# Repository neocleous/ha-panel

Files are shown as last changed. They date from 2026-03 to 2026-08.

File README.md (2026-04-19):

# HA Panel

Wall-mounted Home Assistant touch panel built on Raspberry Pi 5 with a Waveshare 8" DSI display.

HA runs on a separate server. Each panel is a pure display and sensor client — no HAOS on the panel itself.

---

## Hardware

| Component | Part |
|---|---|
| Compute | Raspberry Pi 5 (4GB) |
| Display | Waveshare 8inch DSI LCD (C), 1280×800 IPS |
| Touch controller | AT42QT1070 (custom PCB, I2C, 4 buttons) |
| Temp / humidity / pressure / VOC | BME680 breakout (I2C 0x76) |
| Proximity (screen wake) | VL53L0X breakout (I2C 0x29) |
| Ambient light | VEML6030 breakout (I2C 0x10) |
| Power | USB-C (Adafruit USB Type C Vertical Breakout or custom power board) |

All sensors connect directly to the Pi's I2C bus 1. No sensors are on the touch PCB.

---

## Repository layout

```
ha-panel/
├── sensor-daemon/
│   ├── main.py              # MQTT discovery + I2C polling loop
│   ├── config.py            # Your local config — NOT committed (see .gitignore)
│   ├── config.example.py    # Template — copy to config.py and fill in values
│   ├── backlight.py         # sysfs backlight control
│   ├── requirements.txt
│   └── sensors/
│       ├── at42qt1070.py    # Touch buttons (KEY0–KEY3)
│       ├── bme680.py        # Temp / humidity / pressure / VOC
│       ├── vl53l0x.py       # Proximity (ToF)
│       └── veml6030.py      # Ambient light
├── provisioning-ui/
│   ├── index.html           # Wi-Fi network list
│   ├── password.html        # Password entry + on-screen keyboard
│   └── server.py            # Local HTTP server (port 8080)
└── system/
    ├── install.sh           # Full install script for a new panel
    ├── startup.sh           # Kiosk startup: writes labwc config, launches labwc
    ├── update.sh            # Nightly update script
    ├── panel-update.timer   # systemd timer (2am)
    ├── panel-update.service
    └── sensor-daemon.service
```

---

## Configuration

Before running the sensor daemon, copy the example config and fill in your values:

```bash
cp /opt/ha-panel/repo/sensor-daemon/config.example.py \
   /opt/ha-panel/repo/sensor-daemon/config.py
nano /opt/ha-panel/repo/sensor-daemon/config.py
```

Set at minimum:
- `PANEL_ID` — must match the hostname (e.g. `panel-01`)
- `MQTT_BROKER` — your HA server IP
- `MQTT_USERNAME` / `MQTT_PASSWORD` — MQTT credentials from HA

The HA dashboard URL is set in `/opt/ha-panel/config`:

```bash
HA_URL=http://YOUR_HA_IP:8123
```

**Never commit `config.py` to the repo.** It is listed in `.gitignore`.

---

## Deploying a new panel

### Step 1 — Flash SD card

Use [Raspberry Pi Imager](https://www.raspberrypi.com/software/) with these settings:

| Setting | Value |
|---|---|
| OS | Raspberry Pi OS Lite (64-bit) |
| Hostname | `panel-01` (increment for each panel) |
| Username | *(your chosen username)* |
| Password | *(your chosen password)* |
| SSH | Enable — password authentication |
| Wi-Fi | Configure your network |
| Locale | Set your timezone and keyboard layout |

### Step 2 — Boot and SSH in

Insert the SD card, connect the DSI display, and power on. Wait ~60 seconds for first boot, then SSH in:

```bash
ssh yourusername@panel-01.local
# or use the IP address if mDNS isn't available
```

### Step 3 — Run the install script

```bash
curl -fsSL https://raw.githubusercontent.com/neocleous/ha-panel/main/system/install.sh \
  -o /tmp/install.sh && sudo bash /tmp/install.sh
```

The script will:

1. Detect your username automatically
2. Install all required packages
3. Configure the display overlay, I2C, Bluetooth disable, and autologin
4. Clone the repo to `/opt/ha-panel/repo`
5. Set up the Python venv
6. Configure the firewall
7. Offer to reboot

### Step 4 — Configure the panel

After the install, copy and edit the sensor daemon config:

```bash
cp /opt/ha-panel/repo/sensor-daemon/config.example.py \
   /opt/ha-panel/repo/sensor-daemon/config.py
nano /opt/ha-panel/repo/sensor-daemon/config.py
```

Then create the panel config file:

```bash
sudo nano /opt/ha-panel/config
```

Add:

```
HA_URL=http://YOUR_HA_IP:8123
```

Then reboot. The panel will start automatically.

---

## How it works

### Display stack

```
TTY1 autologin (.bash_profile)
  └── startup.sh
        ├── Sources /opt/ha-panel/config
        ├── Writes ~/.config/labwc/rc.xml  (touch mapping, window rules)
        ├── Writes ~/.config/labwc/autostart  (squeekboard + chromium loop)
        └── Launches labwc
              ├── squeekboard  (on-screen keyboard)
              └── chromium --app=HA_URL (kiosk, maximised, no decorations)
```

### Sensor daemon

Runs as a system service (`sensor-daemon.service`). On startup it publishes MQTT discovery messages so all entities appear automatically in HA under the panel's device. It then polls sensors every ~5 seconds and publishes readings.

Entities registered per panel:

| Entity | Type |
|---|---|
| Temperature | Sensor |
| Humidity | Sensor |
| Pressure | Sensor |
| VOC | Sensor |
| Light | Sensor |
| Proximity | Sensor |
| Button 0–3 | Binary sensor |
| Backlight | Switch |

MQTT topics follow the pattern: `home/{panel-id}/sensor/*`

### Nightly updates

A systemd timer fires at 2:00–2:05am. The update script:

1. Turns the screen off
2. Runs `apt upgrade`
3. Updates `rpi-eeprom`
4. Upgrades Python packages in the venv
5. Pulls the latest repo via `git reset --hard origin/main`
6. Reboots if the kernel or eeprom changed

### Wi-Fi provisioning

If the panel boots without a network connection, `startup.sh` starts the provisioning server on port 8080 and loads `http://localhost:8080` in Chromium instead of HA.

---

## SSH access

Each panel accepts SSH from the local network only (firewall rule: `192.168.1.0/24`).

```bash
ssh yourusername@panel-01.local
ssh yourusername@panel-02.local
```

---

## Adding a second panel to HA

No manual HA configuration is needed. When the sensor daemon starts on a new panel it publishes MQTT discovery messages automatically. The new panel will appear in:

**HA → Settings → Devices & Services → MQTT → Devices**

---

## Troubleshooting

### Touchscreen not working after reboot

Confirm autologin is active:

```bash
sudo raspi-config nonint get_autologin
# Should return: 1
```

### On-screen keyboard not appearing

Chromium must be launched with `--app=URL --start-maximized` (not `--kiosk`). Confirm:

```bash
pgrep -a chromium | grep "app="
```

### Sensor daemon not connecting to MQTT

Check the service logs:

```bash
sudo journalctl -u sensor-daemon --no-pager | tail -30
```

Verify the MQTT credentials in `sensor-daemon/config.py` match those in your HA MQTT integration.

### Backlight not controlled

Find the correct sysfs path:

```bash
ls /sys/class/backlight/
```

Update `BACKLIGHT_PATH` in `sensor-daemon/config.py` to match.

### Display not turning on

Verify the correct overlay is set in `/boot/firmware/config.txt`:

```
dtoverlay=vc4-kms-dsi-waveshare-panel,8_0_inch
```

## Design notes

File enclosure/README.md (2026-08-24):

# Enclosure

`HA Panel Final.step` — full enclosure model (Shapr3D export, 2026-08-24).

Printed on Bambu Lab X1C, 0.4 mm nozzle, 0.2 mm layer height.
Touch-board pocket expects the rev-C PCB (100 x 44 x 1.6 mm, flat front
face, no mounting holes — adhesive/press fit). Clearances are sized for
FDM (0.2 mm); increase to 0.4–0.5 mm before ordering SLS/MJF, resin can
keep 0.2 mm (0.3 mm on long mating edges).

Related: PCB source, BOM and assembly docs in `hardware/rev-c/` on this
branch.

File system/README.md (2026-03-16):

# HA Panel

Wall-mounted Home Assistant touch panel built on Raspberry Pi 5 with a Waveshare 8" DSI display.

HA runs on a separate server. Each panel is a pure display and sensor client — no HAOS on the panel itself.

---

## Hardware

| Component | Part |
|---|---|
| Compute | Raspberry Pi 5 (4GB) |
| Display | Waveshare 8inch DSI LCD (C), 1280×800 IPS |
| Touch controller | AT42QT1070 (custom PCB, I2C, 4 buttons) |
| Temp / humidity / pressure / VOC | BME680 breakout (I2C 0x76) |
| Proximity (screen wake) | VL53L0X breakout (I2C 0x29) |
| Ambient light | VEML6030 breakout (I2C 0x10) |
| Power | USB-C (custom power board) |

All sensors connect directly to the Pi's I2C bus 1. No sensors are on the touch PCB.

---

## Repository layout

```
ha-panel/
├── sensor-daemon/
│   ├── main.py              # MQTT discovery + I2C polling loop
│   ├── config.py            # All configurable values
│   ├── backlight.py         # sysfs backlight control
│   ├── requirements.txt
│   └── sensors/
│       ├── at42qt1070.py    # Touch buttons (KEY0–KEY3)
│       ├── bme680.py        # Temp / humidity / pressure / VOC
│       ├── vl53l0x.py       # Proximity (ToF)
│       └── veml6030.py      # Ambient light
├── provisioning-ui/
│   ├── index.html           # Wi-Fi network list
│   ├── password.html        # Password entry + on-screen keyboard
│   └── server.py            # Local HTTP server (port 8080)
└── system/
    ├── install.sh           # Full install script for a new panel
    ├── startup.sh           # Kiosk startup: writes labwc config, launches labwc
    ├── update.sh            # Nightly update script
    ├── panel-update.timer   # systemd timer (2am)
    ├── panel-update.service
    └── sensor-daemon.service
```

---

## Deploying a new panel

### Step 1 — Flash SD card

Use [Raspberry Pi Imager](https://www.raspberrypi.com/software/) with these settings:

| Setting | Value |
|---|---|
| OS | Raspberry Pi OS Lite (64-bit) |
| Hostname | `panel-02` (increment for each panel) |
| Username | `pi` |
| Password | *(your chosen password)* |
| SSH | Enable — password authentication |
| Wi-Fi | Configure your network |
| Locale | Set your timezone and keyboard layout |

### Step 2 — Boot and SSH in

Insert the SD card, connect the DSI display, and power on. Wait ~60 seconds for first boot, then SSH in:

```bash
ssh pi@panel-02.local
# or use the IP address if mDNS isn't available
```

### Step 3 — Run the install script

You need a GitHub Personal Access Token (PAT) with `repo` read scope to download the script from the private repo. Create one at: https://github.com/settings/tokens

Then run:

```bash
curl -fsSL \
  -H "Authorization: token YOUR_GITHUB_PAT" \
  "https://raw.githubusercontent.com/neocleous/ha-panel/main/system/install.sh" \
  | sudo bash
```

The script will:

1. Install all required packages
2. Configure the display overlay, I2C, Bluetooth disable, and autologin
3. Generate a unique SSH deploy key for this panel
4. **Pause and show you the public key** — add it to GitHub before continuing
5. Clone the repo to `/opt/ha-panel/repo`
6. Set up the Python venv and install sensor daemon dependencies
7. Enable the sensor daemon and nightly update timer
8. Configure the firewall
9. Offer to reboot

### Step 4 — Add the deploy key to GitHub

When the script pauses, it will display the public key and instructions. Go to:

**https://github.com/neocleous/ha-panel/settings/keys → Add deploy key**

- Title: the panel ID (e.g. `panel-02`)
- Key: paste the public key shown by the script
- Allow write access: **leave unchecked**

Press Enter in the terminal to continue.

### Step 5 — Reboot

The script will offer to reboot. After reboot the panel will automatically:

- Log in as `pi` on TTY1
- Launch labwc (Wayland compositor)
- Start Chromium in app mode pointing at HA
- Register all sensors with HA via MQTT discovery

---

## How it works

### Display stack

```
TTY1 autologin (.bash_profile)
  └── startup.sh
        ├── Writes ~/.config/labwc/rc.xml  (touch mapping, window rules)
        ├── Writes ~/.config/labwc/autostart  (squeekboard + chromium loop)
        └── Launches labwc
              ├── squeekboard  (on-screen keyboard)
              └── chromium --app=http://HA_URL (kiosk, maximised, no decorations)
```

### Sensor daemon

Runs as a system service (`sensor-daemon.service`). On startup it publishes MQTT discovery messages so all entities appear automatically in HA under the panel's device. It then polls sensors every ~5 seconds and publishes readings.

Entities registered per panel:

| Entity | Type |
|---|---|
| Temperature | Sensor |
| Humidity | Sensor |
| Pressure | Sensor |
| VOC | Sensor |
| Light | Sensor |
| Proximity | Sensor |
| Button 0–3 | Binary sensor |
| Backlight | Switch |

MQTT topics follow the pattern: `home/{panel-id}/sensor/*`

### Nightly updates

A systemd timer fires at 2:00–2:05am (random stagger between panels). The update script:

1. Turns the screen off
2. Runs `apt upgrade`
3. Updates `rpi-eeprom`
4. Upgrades Python packages in the venv
5. Pulls the latest repo via `git reset --hard origin/main`
6. Reboots if the kernel, eeprom, or repo changed

### Wi-Fi provisioning

If the panel boots without a network connection, `startup.sh` starts the provisioning server on port 8080 and loads `http://localhost:8080` in Chromium instead of HA. The provisioning UI shows available networks and a touch keyboard for password entry.

---

## Configuration

All configurable values are in `sensor-daemon/config.py`:

```python
PANEL_ID = "panel-01"       # Must match hostname
HA_URL   = "http://192.168.1.x:8123"
MQTT_HOST = "192.168.1.x"
MQTT_PORT = 1883
MQTT_USER = "ha-panel"
MQTT_PASS = "your-password"
```

The HA URL and MQTT settings are also hardcoded in `system/startup.sh` and `system/install.sh`. If you change your HA server address, update all three files.

---

## Troubleshooting

### Touchscreen not working after reboot

The touchscreen requires labwc to be started from a proper login session (not a systemd service). Confirm autologin is active:

```bash
sudo raspi-config nonint get_autologin
# Should return: 1
```

Check the labwc process is running and was started from bash (not systemd):

```bash
ps -o pid,ppid,cmd $(pgrep labwc)
# PPID should be a bash shell, not systemd (PID 1)
```

### On-screen keyboard not appearing

Squeekboard only appears above maximised windows, not true fullscreen. Chromium must be launched with `--app=URL --start-maximized` (not `--kiosk`). Confirm:

```bash
pgrep -a chromium | grep "app="
```

### Sensor daemon not connecting to MQTT

Check the service logs:

```bash
sudo journalctl -u sensor-daemon --no-pager | tail -30
```

Verify the MQTT credentials in `sensor-daemon/config.py` match those in your HA MQTT integration.

### Backlight not controlled

Find the correct sysfs path:

```bash
ls /sys/class/backlight/
```

Update `BACKLIGHT_PATH` in `system/startup.sh` to match.

### Display not turning on

Verify the correct overlay is set in `/boot/firmware/config.txt`:

```
dtoverlay=vc4-kms-dsi-waveshare-panel,8_0_inch
```

---

## SSH access

Each panel accepts SSH from the local network only (firewall rule: `192.168.1.0/24`).

```bash
ssh pi@panel-01.local
ssh pi@panel-02.local
```

Cockpit web console is available at `https://panel-01.local:9090`

---

## Adding a second panel to HA

No manual HA configuration is needed. When the sensor daemon starts on a new panel it publishes MQTT discovery messages automatically. The new panel will appear in:

**HA → Settings → Devices & Services → MQTT → Devices**

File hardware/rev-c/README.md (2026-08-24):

# HA Panel — Touch Board rev C

Capacitive 4-button touch board for the wall-mounted Home Assistant panel.
Carries the touch controller and acts as the wiring hub for the panel's I2C
sensor breakouts. Designed 2026-07; fabricated at JLCPCB.

Rev C is a ground-up redesign (KiCad 7, programmatically generated) replacing
the rev-A/rev-B EasyEDA design.

## Specifications

| Parameter | Value |
|---|---|
| Dimensions | 100 x 44 mm, rounded corners r2, 1.6 mm FR-4 |
| Layers | 2 (front: electrodes + bus, back: all components) |
| Finish | ENIG, green mask, white silk |
| Holes | None (tented vias only) — front face is completely flat |
| Touch controller | AT42QT1070-SSUR (SOIC-14), I2C addr 0x1B |
| Electrodes | 4x Ø12 mm top copper, mask-covered (intentional — no exposed metal), 24 mm pitch |
| I2C | No on-board pull-ups; bus relies on host (Pi 1.8k) + breakout pull-ups |

## Design notes / changes vs rev A

- **MODE (pin 2) tied to GND** — hard requirement for I2C mode. Floating MODE
  was the probable root cause of rev A never appearing at 0x1B.
- **4.7k series resistors (R1–R4) added in each KEY sense line** per
  AT42QT1070 datasheet §3.1 (ESD/RFI). Rev A had none.
- **4.7k series resistors in SDA/SCL removed** — with the Pi's 1.8k hardware
  pull-ups they broke logic levels (V_OL ≈ 2.4 V at the host).
- Unused pins (KEY4–6, RESET#, CHANGE#) left unconnected per datasheet;
  disable keys 4–6 in software (AVE/AKS = 0).
- All silkscreen is human-readable: every part carries designator + value,
  every wire pad is net-labelled, U1 has a pin-1 dot.

## Wire pad clusters (bottom edge, viewed from the back)

Left to right: **HOST (PI)** · **BME680** · **VL53L0X** · **VEML6030**
Each cluster: `VCC  GND  SDA  SCL` (labelled). Pads 2x3 mm, 3.5 mm pitch,
sized for 24 AWG (power) / 28 AWG (signal) silicone stranded wire.

All three sensor clusters are parallel drops on the same I2C bus
(0x77 / 0x29 / 0x48; controller at 0x1B — no conflicts).

## Electrode / key mapping

Viewed from the FRONT of the panel, left to right the electrodes are
**KEY3, KEY2, KEY1, KEY0** (routing-optimised order). Map keys to actions
in `sensor-daemon` accordingly.

## Assembly

1. Stencil (bottom side, 0.12 mm) + Sn63/Pb37 no-clean paste (SMD291AXT4).
   Paste apertures exist only for U1, R1–R4, C1, C2 — wire pads are
   intentionally paste-free.
2. Place: U1 (mind the pin-1 dot), 4x 4k7 0402, C1 100n 0402, C2 10u 0603.
3. Hot air ~320 °C, low-mid airflow, until reflow + a few seconds.
4. Solder harness wires to the clusters with an iron (pre-tin wire + pad).
5. Bring-up: power via HOST cluster, then `sudo i2cdetect -y 1` on the Pi —
   0x1B present validates MODE strap, solder and bus in one shot.

## Files

- `ha_touch_revC.kicad_pcb` — board source (KiCad 7). DRC-clean. This is
  the canonical file; the fabrication set regenerates from it exactly:
  `kicad-cli pcb export gerbers ha_touch_revC.kicad_pcb -o gerbers/ \
   --layers "F.Cu,B.Cu,F.Mask,B.Mask,F.SilkS,B.SilkS,B.Paste,Edge.Cuts" \
   --subtract-soldermask` plus
  `kicad-cli pcb export drill --format excellon --excellon-separate-th`.
  The zip as actually ordered (2026-07-26) is archived offline.
- `BOM.csv` — bill of materials with DigiKey part numbers.

JLCPCB order settings: 2 layer, 1.6 mm, ENIG, tented vias, remove mark,
flying-probe test; stencil bottom-only, custom 190x190 mm.

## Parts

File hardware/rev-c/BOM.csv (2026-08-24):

Designator | Qty | Value | Package | Manufacturer | MPN | DigiKey PN | Notes
U1 | 1 | AT42QT1070-SSUR | SOIC-14 | Microchip | AT42QT1070-SSUR | AT42QT1070-SSURCT-ND | Touch controller; I2C 0x1B; MODE tied to GND on PCB
R1-R4 | 4 | 4.7k 1% | 0402 | Yageo | RC0402FR-074K7L | 311-4.7KLRCT-ND | Series resistors in KEY0-KEY3 sense lines (datasheet 3.1)
C1 | 1 | 100nF 16V X7R | 0402 | Samsung | CL05B104KO5NNNC | 1276-1001-1-ND | VDD decoupling at U1
C2 | 1 | 10uF 10V X5R | 0603 | Samsung | CL10A106KP8NNNC | 1276-1192-1-ND | Bulk cap near HOST cluster
J1-J4 (HOST/BME680/VL53L0X/VEML6030) | 16 pads | wire pads | 2x3mm SMD | - | - | - | Not fitted parts; hand-solder harness wires (24 AWG power / 28 AWG signal)
Consumable | 1 | Solder paste Sn63/Pb37 no-clean T4 | 15g syringe | Chip Quik | SMD291AXT4 | SMD291AXT4-ND | Reflow paste; refrigerate 3-8C

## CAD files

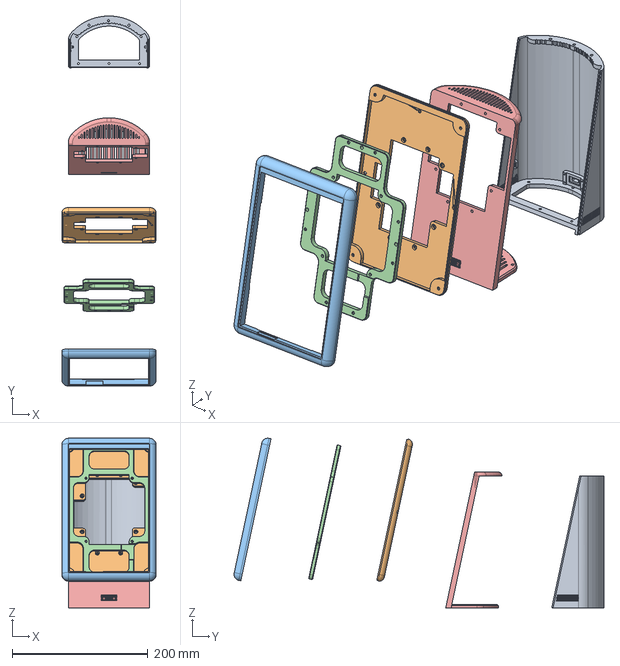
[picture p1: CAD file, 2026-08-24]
enclosure/HA Panel Final.step
139.0 x 545.0 x 249.8 mm

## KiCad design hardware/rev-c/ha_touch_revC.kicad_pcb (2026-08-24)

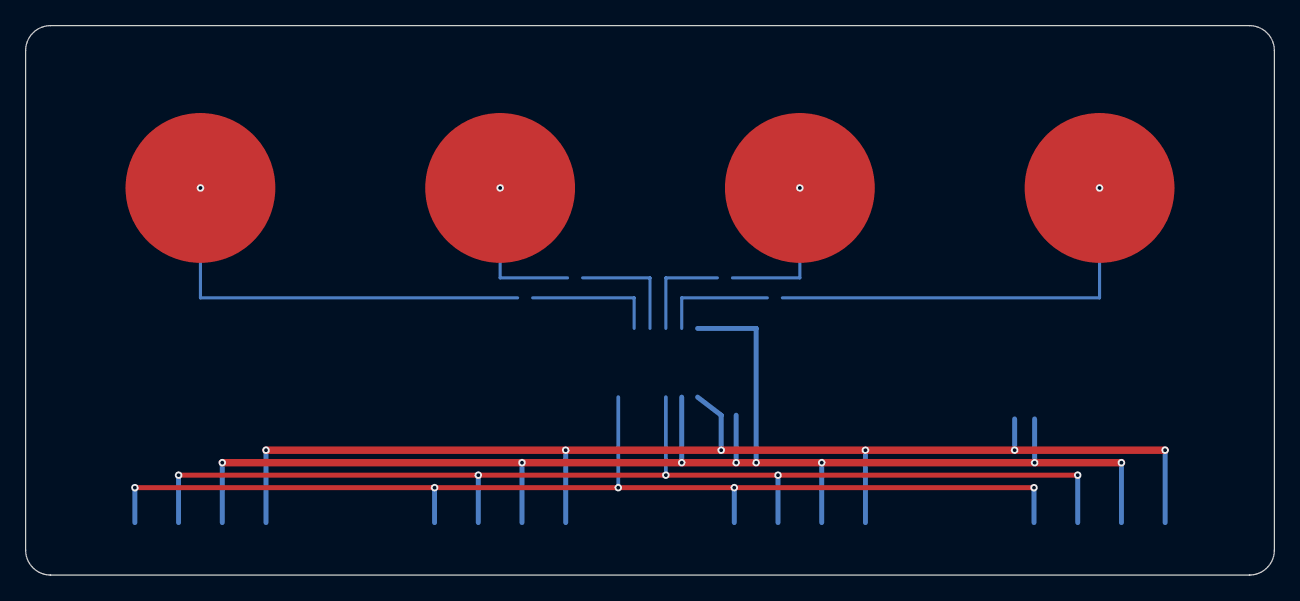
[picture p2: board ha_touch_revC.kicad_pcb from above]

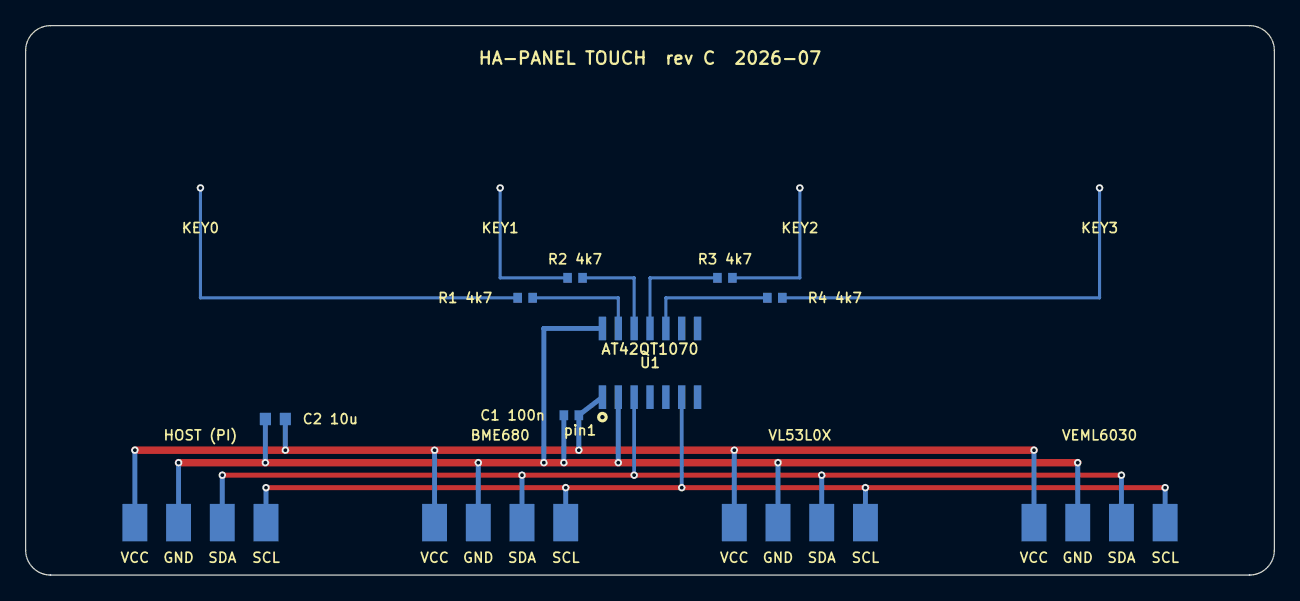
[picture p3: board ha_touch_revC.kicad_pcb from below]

Board: 2 copper layers, 100.0 x 44.0 mm, 15 parts (11 on the bottom side), 12 nets.

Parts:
C1: C1
C2: C2
E0: E0
E1: E1
E2: E2
E3: E3
J1: J1
J2: J2
J3: J3
J4: J4
R1: R1
R2: R2
R3: R3
R4: R4
U1: U1

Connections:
GND: C1.2, C2.2, J1.2, J2.2, J3.2, J4.2, U1.2, U1.14
KEY0: R1.1, U1.13
KEY1: R2.1, U1.12
KEY2: R3.2, U1.11
KEY3: R4.2, U1.10
SCL: J1.4, J2.4, J3.4, J4.4, U1.6
SDA: J1.3, J2.3, J3.3, J4.3, U1.3
SENSE0: E0.1, R1.2
SENSE1: E1.1, R2.2
SENSE2: E2.1, R3.1
SENSE3: E3.1, R4.1
VCC: C1.1, C2.1, J1.1, J2.1, J3.1, J4.1, U1.1

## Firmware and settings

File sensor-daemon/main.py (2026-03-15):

import time
import threading
import json
import smbus2
import paho.mqtt.client as mqtt
import sys
import os

sys.path.insert(0, os.path.dirname(os.path.abspath(__file__)))

from config import (
    PANEL_ID, MQTT_BROKER, MQTT_PORT, MQTT_USERNAME, MQTT_PASSWORD,
    MQTT_TOPIC_ROOT, I2C_BUS, POLL_INTERVAL_TOUCH, POLL_INTERVAL_PROXIMITY,
    POLL_INTERVAL_LIGHT, POLL_INTERVAL_ENV, PROXIMITY_WAKE_THRESHOLD_MM,
    SCREEN_TIMEOUT
)
from sensors.at42qt1070 import AT42QT1070
from sensors.bme680 import BME680
from sensors.vl53l0x import VL53L0X
from sensors.veml6030 import VEML6030
from backlight import set_backlight

screen_on = True
last_proximity_trigger = time.time()
mqtt_client = mqtt.Client(client_id=PANEL_ID, callback_api_version=mqtt.CallbackAPIVersion.VERSION1)

DEVICE = {
    "identifiers": [PANEL_ID],
    "name": f"Panel {PANEL_ID.split('-')[1] if '-' in PANEL_ID else PANEL_ID}",
    "model": "HA Touch Panel",
    "manufacturer": "Custom"
}

DISCOVERY_ENTITIES = [
    {
        "component": "sensor",
        "object_id": f"{PANEL_ID}_temperature",
        "config": {
            "name": "Temperature",
            "state_topic": f"{MQTT_TOPIC_ROOT}/sensor/temperature",
            "unit_of_measurement": "°C",
            "device_class": "temperature",
            "state_class": "measurement",
            "unique_id": f"{PANEL_ID}_temperature",
            "device": DEVICE
        }
    },
    {
        "component": "sensor",
        "object_id": f"{PANEL_ID}_humidity",
        "config": {
            "name": "Humidity",
            "state_topic": f"{MQTT_TOPIC_ROOT}/sensor/humidity",
            "unit_of_measurement": "%",
            "device_class": "humidity",
            "state_class": "measurement",
            "unique_id": f"{PANEL_ID}_humidity",
            "device": DEVICE
        }
    },
    {
        "component": "sensor",
        "object_id": f"{PANEL_ID}_pressure",
        "config": {
            "name": "Pressure",
            "state_topic": f"{MQTT_TOPIC_ROOT}/sensor/pressure",
            "unit_of_measurement": "hPa",
            "device_class": "atmospheric_pressure",
            "state_class": "measurement",
            "unique_id": f"{PANEL_ID}_pressure",
            "device": DEVICE
        }
    },
    {
        "component": "sensor",
        "object_id": f"{PANEL_ID}_voc",
        "config": {
            "name": "VOC",
            "state_topic": f"{MQTT_TOPIC_ROOT}/sensor/voc",
            "unit_of_measurement": "Ω",
            "state_class": "measurement",
            "unique_id": f"{PANEL_ID}_voc",
            "device": DEVICE
        }
    },
    {
        "component": "sensor",
        "object_id": f"{PANEL_ID}_light",
        "config": {
            "name": "Light",
            "state_topic": f"{MQTT_TOPIC_ROOT}/sensor/light",
            "unit_of_measurement": "lx",
            "device_class": "illuminance",
            "state_class": "measurement",
            "unique_id": f"{PANEL_ID}_light",
            "device": DEVICE
        }
    },
    {
        "component": "sensor",
        "object_id": f"{PANEL_ID}_proximity",
        "config": {
            "name": "Proximity",
            "state_topic": f"{MQTT_TOPIC_ROOT}/sensor/proximity",
            "unit_of_measurement": "mm",
            "state_class": "measurement",
            "unique_id": f"{PANEL_ID}_proximity",
            "device": DEVICE
        }
    },
    {
        "component": "binary_sensor",
        "object_id": f"{PANEL_ID}_button0",
        "config": {
            "name": "Button 0",
            "state_topic": f"{MQTT_TOPIC_ROOT}/touch/button0",
            "payload_on": "pressed",
            "payload_off": "released",
            "unique_id": f"{PANEL_ID}_button0",
            "device": DEVICE
        }
    },
    {
        "component": "binary_sensor",
        "object_id": f"{PANEL_ID}_button1",
        "config": {
            "name": "Button 1",
            "state_topic": f"{MQTT_TOPIC_ROOT}/touch/button1",
            "payload_on": "pressed",
            "payload_off": "released",
            "unique_id": f"{PANEL_ID}_button1",
            "device": DEVICE
        }
    },
    {
        "component": "binary_sensor",
        "object_id": f"{PANEL_ID}_button2",
        "config": {
            "name": "Button 2",
            "state_topic": f"{MQTT_TOPIC_ROOT}/touch/button2",
            "payload_on": "pressed",
            "payload_off": "released",
            "unique_id": f"{PANEL_ID}_button2",
            "device": DEVICE
        }
    },
    {
        "component": "binary_sensor",
        "object_id": f"{PANEL_ID}_button3",
        "config": {
            "name": "Button 3",
            "state_topic": f"{MQTT_TOPIC_ROOT}/touch/button3",
            "payload_on": "pressed",
            "payload_off": "released",
            "unique_id": f"{PANEL_ID}_button3",
            "device": DEVICE
        }
    },
    {
        "component": "switch",
        "object_id": f"{PANEL_ID}_backlight",
        "config": {
            "name": "Backlight",
            "command_topic": f"{MQTT_TOPIC_ROOT}/backlight/set",
            "state_topic": f"{MQTT_TOPIC_ROOT}/backlight/state",
            "payload_on": "on",
            "payload_off": "off",
            "unique_id": f"{PANEL_ID}_backlight",
            "device": DEVICE
        }
    }
]

def publish_discovery():
    for entity in DISCOVERY_ENTITIES:
        topic = f"homeassistant/{entity['component']}/{PANEL_ID}/{entity['object_id']}/config"
        mqtt_client.publish(topic, json.dumps(entity['config']), retain=True)

def on_connect(client, userdata, flags, rc):
    if rc == 0:
        publish_discovery()
        client.subscribe(f"{MQTT_TOPIC_ROOT}/backlight/set")
    else:
        print(f"MQTT connection failed: {rc}")

def on_message(client, userdata, msg):
    global screen_on
    payload = msg.payload.decode().strip().lower()
    if msg.topic == f"{MQTT_TOPIC_ROOT}/backlight/set":
        if payload == "on":
            set_backlight(True)
            screen_on = True
            mqtt_client.publish(f"{MQTT_TOPIC_ROOT}/backlight/state", "on", retain=True)
        elif payload == "off":
            set_backlight(False)
            screen_on = False
            mqtt_client.publish(f"{MQTT_TOPIC_ROOT}/backlight/state", "off", retain=True)

def publish(topic, payload):
    mqtt_client.publish(f"{MQTT_TOPIC_ROOT}/{topic}", payload, retain=True)

def touch_loop(sensor):
    while True:
        events = sensor.read()
        for event in events:
            publish(
                f"touch/button{event['button']}",
                event['state']
            )
        time.sleep(POLL_INTERVAL_TOUCH)

def proximity_loop(sensor):
    global screen_on, last_proximity_trigger
    while True:
        distance = sensor.read()
        if distance is not None:
            publish("sensor/proximity", distance)
            if distance <= PROXIMITY_WAKE_THRESHOLD_MM:
                last_proximity_trigger = time.time()
                if not screen_on:
                    set_backlight(True)
                    screen_on = True
                    mqtt_client.publish(f"{MQTT_TOPIC_ROOT}/backlight/state", "on", retain=True)
        if screen_on:
            if time.time() - last_proximity_trigger > SCREEN_TIMEOUT:
                set_backlight(False)
                screen_on = False
                mqtt_client.publish(f"{MQTT_TOPIC_ROOT}/backlight/state", "off", retain=True)
        time.sleep(POLL_INTERVAL_PROXIMITY)

def environment_loop(sensor):
    while True:
        data = sensor.read()
        if data:
            publish("sensor/temperature", data["temperature"])
            publish("sensor/humidity", data["humidity"])
            publish("sensor/pressure", data["pressure"])
            publish("sensor/voc", data["voc"])
        time.sleep(POLL_INTERVAL_ENV)

def light_loop(sensor):
    while True:
        lux = sensor.read()
        if lux is not None:
            publish("sensor/light", lux)
        time.sleep(POLL_INTERVAL_LIGHT)

def main():
    mqtt_client.username_pw_set(MQTT_USERNAME, MQTT_PASSWORD)
    mqtt_client.on_connect = on_connect
    mqtt_client.on_message = on_message
    mqtt_client.connect(MQTT_BROKER, MQTT_PORT, 60)
    mqtt_client.loop_start()

    bus = smbus2.SMBus(I2C_BUS)

    try:
        touch = AT42QT1070(bus)
    except Exception:
        touch = None

    try:
        proximity = VL53L0X(bus)
    except Exception:
        proximity = None

    try:
        environment = BME680()
    except Exception:
        environment = None

    try:
        light = VEML6030()
    except Exception:
        light = None

    threads = []
    if touch is not None:
        threads.append(threading.Thread(target=touch_loop, args=(touch,), daemon=True))
    if proximity is not None:
        threads.append(threading.Thread(target=proximity_loop, args=(proximity,), daemon=True))
    if environment is not None:
        threads.append(threading.Thread(target=environment_loop, args=(environment,), daemon=True))
    if light is not None:
        threads.append(threading.Thread(target=light_loop, args=(light,), daemon=True))

    for t in threads:
        t.start()

    try:
        while True:
            time.sleep(1)
    except KeyboardInterrupt:
        mqtt_client.loop_stop()
        bus.close()

if __name__ == "__main__":
    main()

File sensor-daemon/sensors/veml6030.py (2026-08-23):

import adafruit_veml7700
import busio
import board

# The VEML6030's I2C address is strap-selectable: 0x48 (ADDR high — how the
# panel's breakout is wired) or 0x10 (ADDR low, the VEML7700-compatible
# default). The Adafruit VEML7700 driver defaults to 0x10, which fails
# against a 0x48-strapped board — try both, and say so in the journal
# instead of failing silently.
ADDRESSES = (0x48, 0x10)


class VEML6030:
    def __init__(self):
        self.sensor = None
        self._available = False
        try:
            i2c = busio.I2C(board.SCL, board.SDA)
        except Exception as e:
            print(f"VEML6030: I2C bus init failed: {e}", flush=True)
            return
        for addr in ADDRESSES:
            try:
                self.sensor = adafruit_veml7700.VEML7700(i2c, address=addr)
                self._available = True
                print(f"VEML6030: initialised at 0x{addr:02x}", flush=True)
                break
            except Exception as e:
                print(f"VEML6030: init at 0x{addr:02x} failed: {e}", flush=True)
        if not self._available:
            print("VEML6030: not found — light sensor disabled", flush=True)
            return
        # The sensor sits shaded at the column base and typically reads
        # single-digit lux indoors. The driver default (gain 1/8, 100 ms) has
        # ~0.46 lx/count resolution — hopeless down there. Gain 2 + 200 ms
        # gives ~0.0144 lx/count, saturating around 940 lx, which the shaded
        # aperture will not reach (and clipping just means max brightness).
        try:
            self.sensor.light_gain = adafruit_veml7700.VEML7700.ALS_GAIN_2
            self.sensor.light_integration_time = adafruit_veml7700.VEML7700.ALS_200MS
        except Exception as e:
            print(f"VEML6030: gain config failed (using defaults): {e}", flush=True)

    def read(self):
        if not self._available:
            return None
        try:
            return round(self.sensor.lux, 1)
        except Exception:
            return None

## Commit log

2026-08-23 update.sh V2: config-driven backlight path, protect sensor-config symlink around git reset
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2026-08-23 Fix VEML6030: driver was probing 0x10 only, breakout is at 0x48; log init instead of silently disabling
    [veml6030.py]
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2026-08-24 hardware: add touch board rev C (KiCad source, docs, BOM)
    Ground-up KiCad redesign replacing the EasyEDA rev A/B:
    - MODE pin tied to GND (rev-A I2C failure root cause)
    - 4.7k series R in each KEY sense line per datasheet 3.1
    - SDA/SCL series resistors removed (broke logic levels vs Pi pull-ups)
    - 100x44mm, no holes, flat front face; all parts + labelled wire pad
    clusters on bottom. Ordered at JLCPCB 2026-07-26 incl. bottom stencil.
    [BOM.csv]
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2026-11-01 enclosure: rev E Fusion build scripts + fit/acoustic helpers (2026-11-01)
    Scripts as executed via the Fusion MCP against "HA Panel v5 - tapered" (direct modelling),
    with post-mortem fixes applied (TemporaryBRepManager copy, boss as NEW body + combine).
    Claude-Session: https://claude.ai/code/session_01CLsnQTGKXPber76jnfTvtx
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2026-11-01 enclosure: rev E p18 door plate / slab boss / LCD opening script (boss step fixed)
    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
2026-11-03 enclosure rev F block 1 revision: shell ring + R3.5 inside radius, door inset 6.8, bosses moved, 4 feet off the screws
    Daniel 2026-11-03 21:01: feet option 3 (adhesive, away from the screws), floor edge option 1 with an inside radius,
    slab boss 4a; 21:37: USB-C power stays as designed (5807). Fusion version 'rev F WIP 2026-11-03 b1r',
    f3d revF-wip-b1r.f3d. HOUSING_E 254.22 cm3, DOOR_F 30.92 cm3; interference 0; door-to-ring gap 0.300;
    wall and bend 2.50-2.51. b1r scripts exec() ~/Documents/v5f_common.py (copy of the repo file).
    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
2026-11-04 enclosure rev F R1: rear door split at y -55, solid floor, edge magnets, M3 from below, USB-C bottom centre
    - R1a floor: Pi insert holes, 10 x 10 intake, 4 SJ5012 recesses, 4 door-screw holes
    - R1b split: front shell + rear door (0.3 joint gap), lip in the cavity layer 0.2...1.4 with root band, lane notches
    - R1c 10 magnet pairs D8 x 1.5 across the lap; door bosses with Ruthex M3; USB-C slot and 5807 envelope
    - R1d checks: 45 interference pairs 0, removal sweep 0 from 1 to 80 mm, joint scans, magnet probes
    - R1e/R1f renders, named version and f3d
    - README: rows, lesson 19, R1 checkpoint
    Claude-Session: https://claude.ai/code/session_01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
2026-11-04 enclosure rev F R2: separate speaker boxes, chamber walls removed, insertion paths verified
    - SPKBOX_L 25.321 / SPKBOX_R 25.071 cm3: 1.5 walls, speaker on the front wall (2 pegs + 2 clamp tubes,
    stop pads set both foam layers to 0.7), +x sealed USB-A plug pocket; air 88-118 cm3 per side
    - shell: chamber partitions/ceilings removed (cheeks keep the touch-PCB retention), baffle stop pads,
    Ø2.5 pilots for M3x10 DIN912 self-tapping; front 265.519 -> 238.880 cm3
    - checks: interference 0 except the designed pegs and the basket-envelope rear end (bench: basket <= Ø32
    over its rear 10 mm); box path 0 at 1 mm steps with a 40 mm entry offset and 6 lift; Pi path 0 with
    a 2.0 lift; clamp-key p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
2026-11-04 enclosure rev F block 3: top edge R3, top wall >= 2.5, mic strips/ports/pins, VEML pocket, LD2410C cradle
    - D2: REF_F_outer = rev E generator re-run with the top edge R3 (diff only at the edge), applied to the front
    shell; inner top edge R1; wall >= 2.5 above z 165 via the 2.5 skin of REF_F_outer (fixes a 0.08 mm wall)
    - mic strip pockets 30.4 x 6.4 x 0.8, ports D1.5 at x_rel +-35.5, heat-stake pins D1.8 x 3.5; VEML6030 pocket
    and lux port D2 at +46 (provisional, board unmeasured)
    - LD2410C cradle on the corner bisector (59 deg; the brief's 40 deg surface does not exist), LOS rays logged
    - version "rev F WIP 2026-11-04 b3 ..." saved, revF-wip-b3.f3d 25.6 MB; README rows, lessons 25-27, c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
2026-11-05 enclosure rev F block 6w: decision 1 (a) wall 2.52 normal outside the lap, decisions 2 (a) / 3 (a) recorded
    Daniel 2026-11-05 11:18: "1. a 2. a 3. a".
    - 1 (a): plastic down to 3.22 below the cloth face where the shell leans (TOOL_outer_skin_3p22_F ∩ cavity inside the D1
    surface), outside the lap band, chin, slot zone and sensor windows; openings taken out of the fill; one JOIN per part.
    Front 239.797 -> 240.888 cm3, door 50.601 -> 51.101 cm3. The exact 3.2 skin failed (near-zero sheet on vertical walls,
    fill faces in the planes of earlier cuts): B6w-2 / 2b / 2c kept as the record, lessons 48-50.
    - Matrix: same 72 non-zero pairs as B6m (door x MAIN_back_env 0.74 -> 1.04, BME680_env x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
2026-11-05 enclosure rev F cap block c1 step 1: screwed top cap clamping the cloth, spline groove ledge, posts
    Daniel 2026-11-05 13:31 / 13:51 ("1. A 2. A 3. a"): the top above the cloth line becomes a cap screwed on from the top
    (4 x ISO 10642 M3 x 8 into Ruthex inserts, heads flush), clamping the cloth on a ledge of the front shell; a Ø1.8 TPU
    spline in a 2.8 x 2.5 groove in the ledge holds the cloth while the cap is tightened. Joint 3.0 behind the slab's back
    face (y -22.5 / -22.6). Upper exhaust row moved to z 162.5-165.5. Cap 8.942 cm³, front 235.655 cm³; all intersections 0.
    Saved as Fusion version "rev F WIP 2026-11-05 c1 step 1: ...". Step 2 (sensors into the cap, VEML move, checks, STEP)
    st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
2026-11-05 enclosure rev F audit: a1a records shell-volume errors
    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
2026-11-05 enclosure rev F audit: tool lines crop the fixed bodies (REGION)
    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
2026-11-06 rev F audit response (d-round): scripts d0-d7, README rows, lessons 62-68, checkpoint
    Bracket from below, +x box bore, touch-PCB clips, cooler deflector, door / grommet / cradle
    fixes (flange, stub, pin holes, USB-C opening + collar, floor pads, webs), front small fixes
    (voids, magnet skins, Pi seats), vents (intake 1 492 mm2, door slots 1 504 mm2), exhaust posts,
    shelf land, LD2410C ribs, root fillets, cap pads; full matrix and sweeps; STEP / f3d export.
    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
2026-11-06 rev F d13b-d14: microSD floor hatch (option 1)
    The card is pulled 15.4 toward -x into a pocket in SPKBOX_R's inboard-bottom
    corner and drops out through a 17.7 x 13.0 slot in the floor, door on.
    SPKBOX_R 25.5694 (chamber 117.424 / 85.527, sealed, added material inside
    the old chamber air), front 234.7010, new HATCH_COVER 0.5860 (snap catches)
    and SD_SLED 1.1956 (refit tool). Card paths, tweezers zones and sled path
    clear; changed-pairs matrix as in d7 / d12. d13b: the Pi on its edge does
    not fit. Lesson 62 extended (loader run()).
    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
2026-11-06 rev F d15a-d16h: microSD finger notch in the right speaker box (blocked)
    - d15a: extender route probe (not taken)
    - d16a, d16d: finger channel + card slot in SPKBOX_R, box top +6 mm where its
    B5j-3 path allows; floor hatch, cover, sled and the right floor tie bridge removed
    - d16b, d16c: notch checks (way in and its clear width, channel, grip end,
    card out, exhaust window), changed-pairs matrix
    - d16f: the tie bridge's 0.1 mm fin removed
    - d16e, d16g: versions, f3d, STEP
    - d16h sections: the main-board bracket's right column and foot stand behind
    the channel's inboard half, so a straight finger cannot reach the card;
    fix open (Daniel)
    - README: rows, lessons 74-76, d16 checkpoint
    Co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
2026-11-07 print audit d19: printed-component fits and facing-face clearances (P9)
    - fusion/pa3_bodies.py: body list with box gaps to each print (read-only).
    - fusion/pa3_compfits.py: B-rep minimum distance from each print to 47 current
    component bodies, meshes of those within 0.6 mm; reads the design model
    without activating it (read-only).
    - offline/pa_fits_verify.py: winding-number re-test of pa_fits.py's negative
    spots (all sign errors at edges).
    - offline/pa_fits2.py: facing-face clearances with confirmed inside tests,
    contact and gap regions, area bands; printed and printed-component pairs.
    - RUNS.md: the three Fusion runs (incl. the final check re-run at 02:43) and
    the two offline scri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
2026-11-07 print audit d19: speaker-box support split and views (F12 correction)
    pa_box_support_split.py classes the boxes' tree supports by where they
    stand (chamber, screw-tube bores, outside); pa_box_views.py draws the
    sections and the front wall's first layer. Box R's extra support is
    outside the chamber; inside, one small tree sits deep in the hump pocket.
    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
2026-11-07 Main board + mic strip schematics (electronics block 1, checkpoint 1)
    KiCad 9.0.9 projects:
    - hardware/main-board: 20 V inlet + TPS16630 eFuse, NID100-5 with the
    Mean Well EMC circuit, Pi USB-C output (USB4105) and radar branch,
    TPS70933 3.3 V LDO, GPIO landing (13 wire pads), radar/touch XH,
    D4a echo-reference links (DNP), TAS5756M stereo BTL (DigiAMP+ wiring).
    - hardware/mic-strip: MSM261DHP006 strip (one design, two boards).
    Schematic PDFs, ERC reports (0 errors), value notes with sources,
    GPIO lead table and plug maps (gpio-leads.md), generator scripts.
    Claude-Session: https://claude.ai/code/session_01CLsnQT2xs75Rnv1bP8dfrf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
2026-11-07 Main board routed: 4-layer, DRC 0 errors / 0 unconnected, parity clean (electronics block 2)
    - TAS5756M escape: staggered fan-out rows, PVDD bridges + vias, bootstrap caps moved
    (C104/C115 over pins 4-5/44-45, C108/C111 upright past pins 1/48), courtyard trimmed
    - Pre-routes (amp outputs 0.6 mm, PVDD, 20 V inlet), Freerouting 2.5.0, maze-router fixes,
    GND pours with stitching vias, dangling-via clean-up, silk reference placement
    - R14 moved to the J3 landing; TP18 dropped (PVDD probed at F5 pin 2)
    - Schematic regenerated (TP18), ERC 0/0; DRC report, renders, NOTES section 7
    Claude-Session: https://claude.ai/code/session_01CLsnQT2xs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
2026-11-07 Mic strip: IM69D120 + wire pads, laid out on the K21 strip, DRC clean (electronics block 2)
    - Decision 8.1: MK1 = Infineon IM69D120V01 (bottom port through the strip, Ø0.8 port at 2.0 mm)
    - Decision 9 option 1 (recommended, awaiting confirmation): 5 soldered wire pads instead of
    BM05B-SRSS-TB; JP1, TP1-TP4 and R3 dropped; L/R from the cable SEL strap via R5
    - 28 x 6 x 0.8, 2 layers, all parts on the back, heat-stake holes Ø2.0 at 7.5/26.0 with
    Ø3.6 back keep-outs; maze-routed; ERC 0/0, DRC 0 errors / 0 unconnected, parity clean
    Claude-Session: https://claude.ai/code/session_01CLsnQT2xs75Rnv1bP8dfrf
2026-11-07 rev F e1: main-board outline study (all SMD on the front) - board_zone/
    Read-only body list and world meshes of version 37 (d22) without activating the design, then y-ray column maps at the
    board plane (slab, door sweep, front and back gaps, 1.0 mm to fixed parts, keep-outs and the door). At the current plane:
    outline T 6,139 mm2 (5,940 usable) and maximum 6,876 mm2 (6,674), no hole, connector or print change; plane moves
    tabulated. Answer: Project doc claude/report-main-board-outline-2026-11-07.md.
    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
2026-11-07 Main board rev 2: every SMD part on the front, 90 x 55 (base of outline T), DRC clean
    - Daniel 2026-11-07 22:48: no SMD on the back; board grows (design chat outline T, ca96301)
    - All former back parts re-placed on the front next to their pins; back keeps J2, LK1,
    through-hole joints and bare test pads; T's tab stayed empty and was cut off
    - Re-routed (pre-routes, Freerouting, fixes in gen/fix_main1s.py); DRC 0 errors,
    0 unconnected, parity clean; MAIN_env rev 2 with outline and height zones
    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
2026-11-07 rev F e2: main board rev 2 in the model (MAIN_env rev 2, 733cb5a) - checks, door, lead reach
    Version 38: MAIN_pcb 90 x 55 (z 34-89, -x top corner cut), MAIN_front_env 30 (24.2 below z 35.8) without the K5 corner,
    MAIN_back_env 2.9 + J2 3.5 without the bare top corners; previous bodies hidden as MAIN_*_e2. Checks against 90 bodies:
    no new interference (door 1.77 mm at the +x top corner, sweep 4.18; cap-key lanes 0.20 behind the top edge). Front-face
    leads: J1, J5, J8, J9 can be plugged after mounting; J6 tight because of C7 (as on the 90 x 50 board).
    Answer: Project doc claude/report-main-board-rev2-checks-2026-11-08.md.
    Claude-Session: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
2026-11-08 Main board rev 2.1: C7 to the top strip above the NID, so every front lead plugs after mounting (MAIN_env rev 2.1)
    Design chat reach check (ad90a43): C7 (Ø5 x 12.5) between the NID and J6 kept a fingertip off
    J6's plug. C7 moves to the top strip: body centre (50.67, -2.05), world (-5.67, 86.05). Same part,
    nets and footprint; its pads reach In2 +5V and In1 GND directly, so no track changed.
    DRC: 0 errors, 0 unconnected, parity clean (2 known library-override warnings, J2 and J4).
    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
2026-11-08 rev F e3: main board rev 2.1 - C7 in the model, vent and reach checks pass
    Version 39: MAIN_C7_env (D5.5 x 12.5 at x_rel -5.67, z 86.05, top strip above the NID) and KO_C7_vent (3 mm above
    the vent), hidden. Both touch only the main-board envelopes; nearest other body 20.9 mm (LCD 5 V lead). Reach re-run on
    the rev 2.1 board file: a D24 fingertip reaches J1, J5, J6, J8 and J9 after mounting (J6 no longer tight).
    Answer: Project doc claude/report-main-board-rev2-1-checks-2026-11-08.md.
    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
2026-11-08 Block 3, part 2: DigiKey BOM (55 lines, CHF 169.97 excl. VAT, seen 2026-11-08) and purchase fields in the schematics
    - hardware/notes/digikey-bom.md / .csv: main board, two strips, XH harness, system parts kept from rev 4, the five
    parts moved from AliExpress; part number, need, buy (spares), unit CHF, stock; quick-add CSV with "HA panel".
    - In-stock substitutes for out-of-stock generic passives (several Samsung/Yageo/Murata/TDK lines at 0 stock).
    - U2 TPS70933DBVR (0 stock, 26 wk) -> TPS70933QDBVRQ1 (same DBV pinout, SLVSCE6D); PCB value updated.
    - Strip ESD: TPD1E05U06DYAR at 0 stock -> decision 10 (ESD321DYAR, reversed DYA pinout) pending; schematic unchanged.
    - Schematics: MPN / Manufa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
2026-11-08 Mic strip, decision 10.1: ESD321DYAR for D1-D3 (TPD1E05U06DYAR 0 stock, 26 weeks)
    - ESD321DYA symbol in lib/ha_panel.kicad_sym (DYA pinout: pin 1 GND, pin 2 IO);
    schematic regenerated by gen/mic_strip.py, UUIDs unchanged
    - D1-D3 turned 180 deg with swapped pad nets (gen/fix_esd321.py); copper unchanged,
    silk pin-1 bracket at the GND pad
    - ERC 0/0; DRC 0 errors, 0 unconnected, parity clean, 2 known warnings (MK1, U1)
    - fab files, schematic PDF and 3D render regenerated
    - BOM note: decision 10 recorded as option 1; total unchanged at CHF 169.97 excl. VAT
    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
2026-11-09 Touch board rev D fab set and BOM rows; one stencil for main front + touch back (D56, D57)
    - touch-board: purchase fields injected (U1 from Daniel's stock, D56; C1, C2, R1-R4 on the
    frozen DigiKey basket lines), library nicknames fixed (12 parity warnings cleared), ERC 0/0,
    DRC all severities 0/0/0; JLC fab set fab/touch-board-jlc-2026-11-09.zip (2L, 1.6, ENIG)
    - stencil: hardware/stencil/ - generated stencil-only board with the main board's front paste
    and the touch board's back paste mirrored 10 mm below; F.Paste + Edge.Cuts zip; checked pad by
    pad and gerber flash by flash against both boards
    - notes/jlc-fab.md rev 2026-11-09: touch-board column, combined stencil line, no stencil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
2026-11-10 Main board rev 3: change list and floor plan for the site behind the display (step 2, blocks 0-1; nothing routed)
    Outline 87.0 x 57.9, four holes dia 3.2 for M3 x 8, every part on the door-side face.
    32 site rules checked (main-board-site-2026-11-10 issue 2): 30 met, 2 not met (radar socket 5.6 below its
    span, VEML6030 header 11.5 below zone E's probed point; both because of the supply module).
    rev3/: README (report), floorplan.png, plan board, site numbers, placement and check scripts.
    Claude-Session: https://claude.ai/code/session_01CLsnQQzqZRsCEYxKPx6bo5
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2026-11-11 Main board rev 3: schematic and routed board for the site behind the display (step 2, block 2)
    Schematic rev 3: M3 mounting holes, sensor header split into J10 (BME680) and J11 (VEML6030), J3 pads in the order
    of the three Pi housings, own wire-pad footprints for J3/J4/J7. ERC 0 errors, 0 warnings.
    Board: 87.0 x 57.9, four layers, routed on the approved floor plan with no part moved; amplifier copper of rev 2.1
    carried over with the block; right speaker pair 1.0 wide on the back; no outer copper under screw heads and post
    faces (H2 back: amplifier tracks under the rim of the post face, noted for the enclosure chat).
    DRC with schematic parity: 0 errors, 0 unconnected, 0 parity issues, 2 warn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
2026-11-11 Main board rev 3: reply to the enclosure chat, height file and STEP files (step 2, block 3)
    - main-board-rev3-reply-2026-11-11.md: outline and holes, heights on both faces, connector table, bench-soldered
    leads, what does not fit with the missing dimension, part changes against rev 2.1.
    - MAIN_env.md for rev 3 (outline, holes, heights).
    - main-board-rev3.step: populated board in the site's frame (KiCad library shapes; envelope blocks for the supply
    module, coils, large fuses, wire link and the capacitors whose library shape is lower than the part).
    main-board-rev3-plug-envelopes.step: plug and lead-bend envelopes over the seven plugged sockets.
    - gen/step_rev3.py makes both; rev3/sitec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
2026-11-11 Main board rev 3.1, block 1: the layout (top right hole, BME680 and VEML6030 headers, wider supply copper, ground pours)
    - H2 from u +30.00 to u +19.20 (v +25.00), inside the enclosure's new zone; keep-out circles moved with it.
    - BME680 header J10 3.90 further from the radar socket; VEML6030 header J11 1.00 lower.
    - Eight small parts moved to make room (R26, R27, F3, C10, TP12, F4, C11, TP3); 109 of 120 parts did not move.
    - The Pi's 5 V board copper 7.2 -> 4.8 mOhm; 20 V inlet copper widened; ground pours on both outer layers with 42 stitching vias.
    - Schematic check clean; board check with schematic comparison: 0 errors, 0 open, 0 differences, 2 warnings as on rev 3.
    - Site rules: 36 chec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
2026-11-11 Main board rev 3.1, block 2: reply to the enclosure, tables, lead notes, STEP files
    - main-board-rev3-1-reply-2026-11-11.md: everything that moved old -> new, holes, heights, back face, connectors,
    probe points, STEP files, the enclosure's two questions, what does not fit, part changes (none).
    - main-board-rev3.1.step and main-board-rev3.1-plug-envelopes.step (X = u, Y = v, Z 0 = back face). The rev 3 files
    are unchanged. Read back by rev3.1/check/step_check.py: holes and all 85 parts agree with the board file.
    - MAIN_env.md for rev 3.1 (rev 3's is rev3/MAIN_env.md). gpio-leads.md: the 13 Pi signal wires enter from the back
    face and are soldered on the door side (rev 3's is rev3/gpio-l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
2026-11-11 Enclosure step 3 repeated, part 1: library, wrapper, STEP import for main board rev 3.1; lead routes
    - v5f_i_lib.py: the h library with this pass's data folder (fp/step3r), purge() and run_h().
    - v5f_i_wrap.py: the h scripts run again unchanged, with every text replacement listed.
    - v5f_i1a_step_import.py: fetches the rev 3.1 STEP files (sha256 checked), imports them, compares the solids with rev 3's.
    - step3r/h3_routes.json: all 14 lead routes; LEAD_BME680 and LEAD_VEML are new, the other 12 are those of step3.
    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
2026-11-11 Enclosure step 3 repeated, part 1: results, lead table, scripts and tool lessons 125-131 (step3r/README.md)
    Stands in for a section of enclosure/fusion/revF/README.md, which is too large to amend through the GitHub connector.
    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
2026-11-12 Enclosure close (part 2): README, j library and wrapper
    Close of the enclosure work, blocks 5 to 7: results in short, lessons 132-139,
    the j library and the wrapper that runs earlier scripts on the model as it stands.
    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
2026-11-12 Enclosure close (part 2): envelopes (j5b) and the right box's leftover sheet (j6f)
    j5b drops the coarse Pi envelope and replaces the touch board's by its seven real
    back parts (version 54). j6f takes the 0.4 sheet out from under the right speaker
    box's raised roof by an extrude cut of its top face on a copy (version 55).
    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
2026-11-12 Enclosure close (part 2): interference matrix, first form (j6a)
    Kept because j6a2 continues its cache table. Slow for pairs with a big body
    (lesson 133).
    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
2026-11-12 Enclosure close (part 2): interference matrix, distance first and big bodies in slabs (j6a2)
    98 bodies, 4 753 pairs, 78 not zero. Lessons 133 to 135.
    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
2026-11-12 Enclosure close (part 2): pictures of the rim with the cloth turned under the edge (j5c)
    Six shots from temporary bodies; they replace the pictures of 2026-11-10 that
    show the cloth cut at z 2.8.
    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
2026-11-12 Enclosure fix pass: k2a tip figures (read-only, with a what-if for the front feet)
2026-11-12 Enclosure fix pass: k1a block 1 build (shell holes and tabs tilted 10 deg, carrier edges, notches in the LCD opening)
2026-11-12 Enclosure fix pass: k1b tab relief for a proud insert; k_pic picture and tool-template helpers
2026-11-12 Enclosure fix pass: k2b block 2 build (plate: lowered band widened under the side walls, front feet moved forward)
2026-11-12 Enclosure fix pass: k2c band tool from the wall's sampled inner edge (replaces k2b's moved-copies tool, which did not finish)
2026-11-12 Enclosure fix pass: k2c band tool - the wall's edge is run on past its end instead of wrapping round it (keeps the field's edge convex); samples and tools cached
2026-11-12 Enclosure fix pass: k3a lead tools (routes as nodes, trial bodies, distances, swap)
2026-11-12 Enclosure fix pass: k3b lead record and checks; k3_routes.json (all 16 leads as routed in block 3)
    Claude-Session: https://claude.ai/code/session_01CLsnQQ8bratfKLiKX9A8ML
2026-11-12 Enclosure fix pass: k3_routes.json - Pi power cable's lap moved behind its own plug (the first lap ran through the plug's envelope)
    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
2026-11-12 Enclosure fix pass: k4a whole-unit checks (way in, ride-in with lead parts, left box slide, reach, matrix, chambers)
    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
2026-11-12 Enclosure fix pass: k4b - lead parts that ride in with the display module (corrected boxes), plate unit's way out for service
    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
2026-11-12 Enclosure fix pass: k3_routes.json - USB lead's end at the ReSpeaker turns on a radius of 4 inside the lengthened side notch; loop 1.7 lower to keep 240
    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
2026-11-12 Enclosure fix pass: README (versions 56-60, scripts, results in short, lessons 146-157)
    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
2026-11-12 Ribbon pass: v5f_m_lib.py - flat leads as strips (straight, bend through the thickness, fold, twist), clearances against every current body, the ADT USB-C plug from the sheet's tables
    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
2026-11-14 Main board rev 3.2, blocks 0 and 1: relief in the +u side edge
    Relief at u +42.0 over v +1.5 to +13.0 (1.5 deep), inner corners r 1.0,
    side walls at v +0.5 and +14.0. No part moved. For it: the amplifier's
    GPIO2 via 1.10 inward beside R105, the I2C pair's loop on the back face
    laid inside the new edge, the pours follow the edge at 0.30 (Daniel's
    decision 2026-11-14, rev3.2/block0.md).
    ERC 0/0; DRC 0 errors, 0 open, 0 parity, 2 warnings as rev 3.1.
    Site rules 41 checked, 39 met (the 2 accepted). Supply copper as rev 3.1.
    Rev 3.1 kept in rev3.1/ (board file, reports, schematic PDF).
    Claude-Session: https://claude.ai/code/session_01CLsnQ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
2026-11-14 Main board rev 3.2 placed in the enclosure model (version 63, g18): the connector calls as run with their results, README with lessons 175-180
    Only the board's solid replaced (the STEP's part solids equal the model's part bodies); relief at the reply's corner points; sleeve, pliers' line, flat leads, ride-in and the fab's outline tolerance checked; interference as version 62. No printed part changed.
    Claude-Session: https://claude.ai/code/session_01CLsnQQb2awKioq4yNDtDZu
